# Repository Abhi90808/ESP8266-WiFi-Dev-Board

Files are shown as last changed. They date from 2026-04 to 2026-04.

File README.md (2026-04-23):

# ESP8266 WiFi Development Board

A custom ESP8266-based WiFi development board designed in KiCad 8, featuring onboard USB-to-serial, 3.3V regulation, and a breadboard-friendly pinout — perfect for IoT prototyping.

---

## Features
- ESP8266 (ESP-12E/F module) WiFi MCU
- Onboard USB-to-Serial (CH340G)
- 3.3V LDO regulator (AMS1117-3.3)
- Auto-reset circuit for one-click flashing
- All GPIO pins broken out to 2.54mm headers
- Flash and Reset buttons onboard
- Power LED and user LED (GPIO2)

## Specifications

| Parameter | Value |
|---|---|
| Module | ESP-12E / ESP-12F |
| MCU | Tensilica L106 (32-bit) |
| Clock Speed | 80MHz / 160MHz |
| WiFi | 802.11 b/g/n (2.4GHz) |
| Operating Voltage | 3.3V |
| USB Input | 5V via Micro USB |
| Flash Memory | 4MB |
| GPIO Pins | 11 usable |
| PCB Layers | 2 |
| Designed With | KiCad 8 |

## Project Structure

```
├── Schematic/       # KiCad schematic (.kicad_sch, PDF)
├── PCB/             # PCB layout (.kicad_pcb, .kicad_pro)
├── Gerbers/         # Fabrication files
├── BOM/             # Bill of materials (CSV)
├── 3D/              # 3D model (.step)
└── Images/          # PCB renders and schematic screenshots
```

## How It Works

The CH340G converts USB to UART for programming. The auto-reset circuit uses transistors on the DTR/RTS lines to automatically pull GPIO0 LOW and reset the ESP8266 before flashing — no manual button pressing needed.

## Programming

1. Install the ESP8266 board in Arduino IDE via Boards Manager
2. Select **Generic ESP8266 Module** or **NodeMCU 1.0**
3. Connect via Micro USB and select the correct COM port
4. Upload directly — auto-reset handles the rest

## Bill of Materials (Summary)

| Component | Value | Qty |
|---|---|-----|
| WiFi Module | ESP-12F | 1 |
| USB-Serial IC | CH340G | 1 |
| LDO Regulator | AMS1117-3.3V | 1 |
| Capacitors | 100nF, 10µF | 4 |
| Transistors | BC817 | 2 |
| Buttons | Tactile | 2 |
| USB Connector | Micro-B | 1 |

## Fabrication

Gerber files are in `/Gerbers`, ready for JLCPCB, PCBWay, or similar.

## License

This project is licensed under the [CERN Open Hardware Licence Version 2 - Strongly Reciprocal (CERN OHL-S v2)](https://ohwr.org/cern_ohl_s_v2.txt).

## Author

**Abhi90808** — [GitHub Profile](https://github.com/Abhi90808)

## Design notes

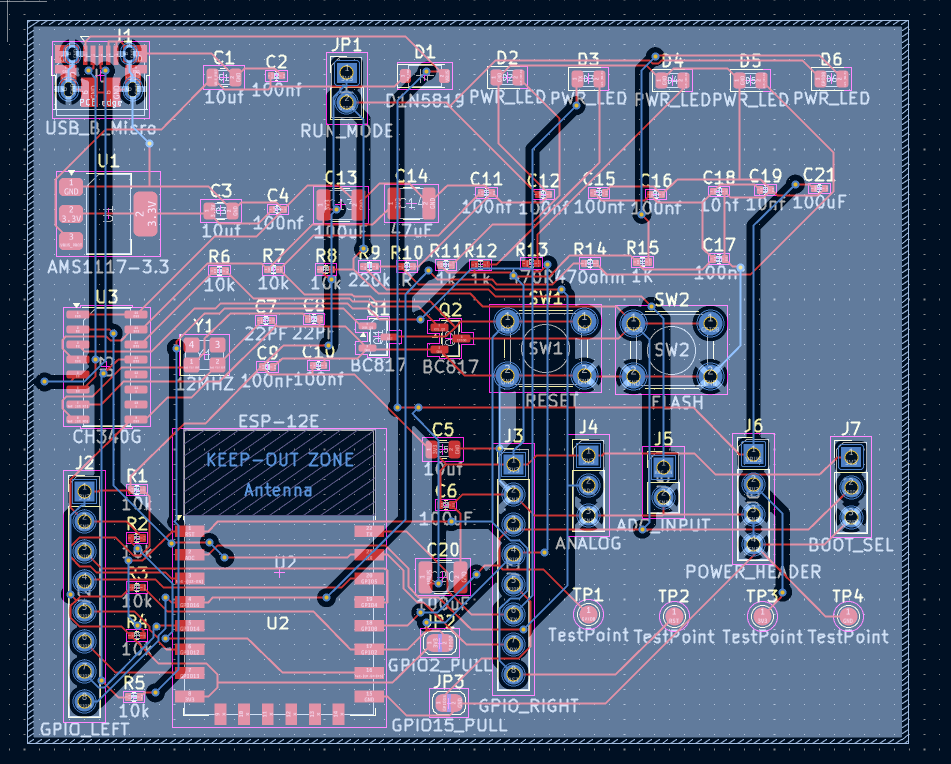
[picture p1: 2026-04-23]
Screenshot 2026-04-21 175008.png

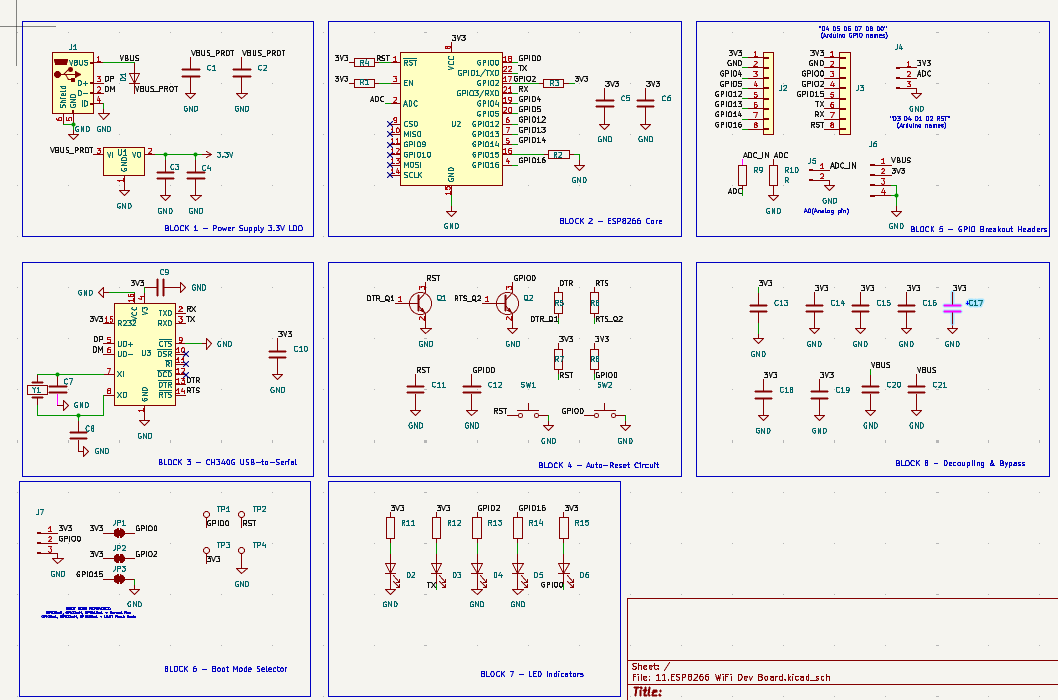
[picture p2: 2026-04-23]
Screenshot 2026-04-21 175130.png

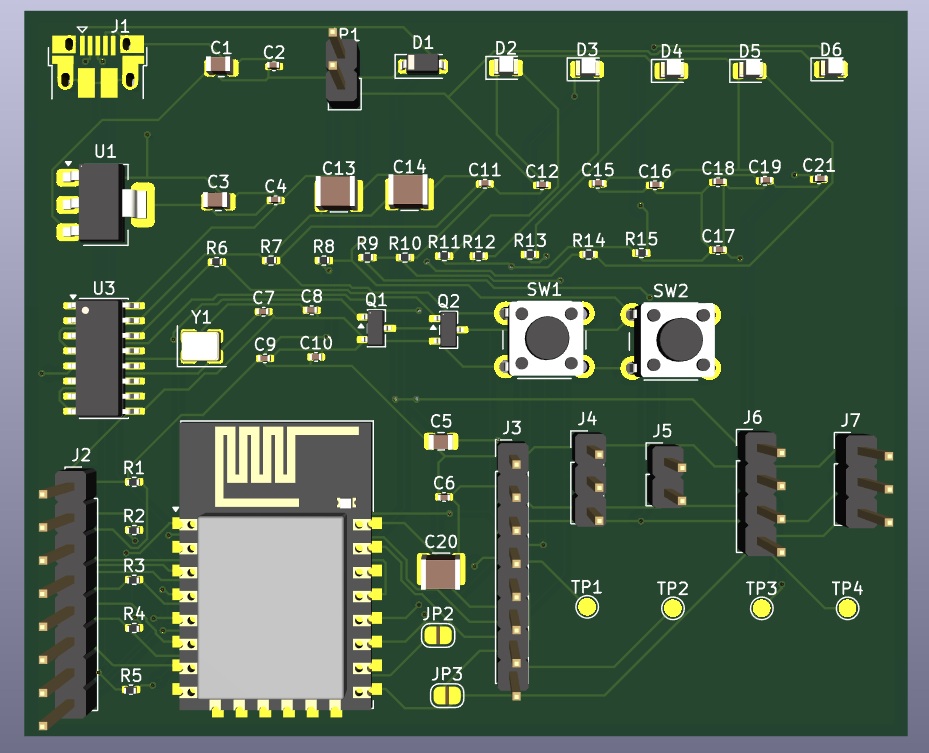
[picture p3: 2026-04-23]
Screenshot 2026-04-21 175057.png

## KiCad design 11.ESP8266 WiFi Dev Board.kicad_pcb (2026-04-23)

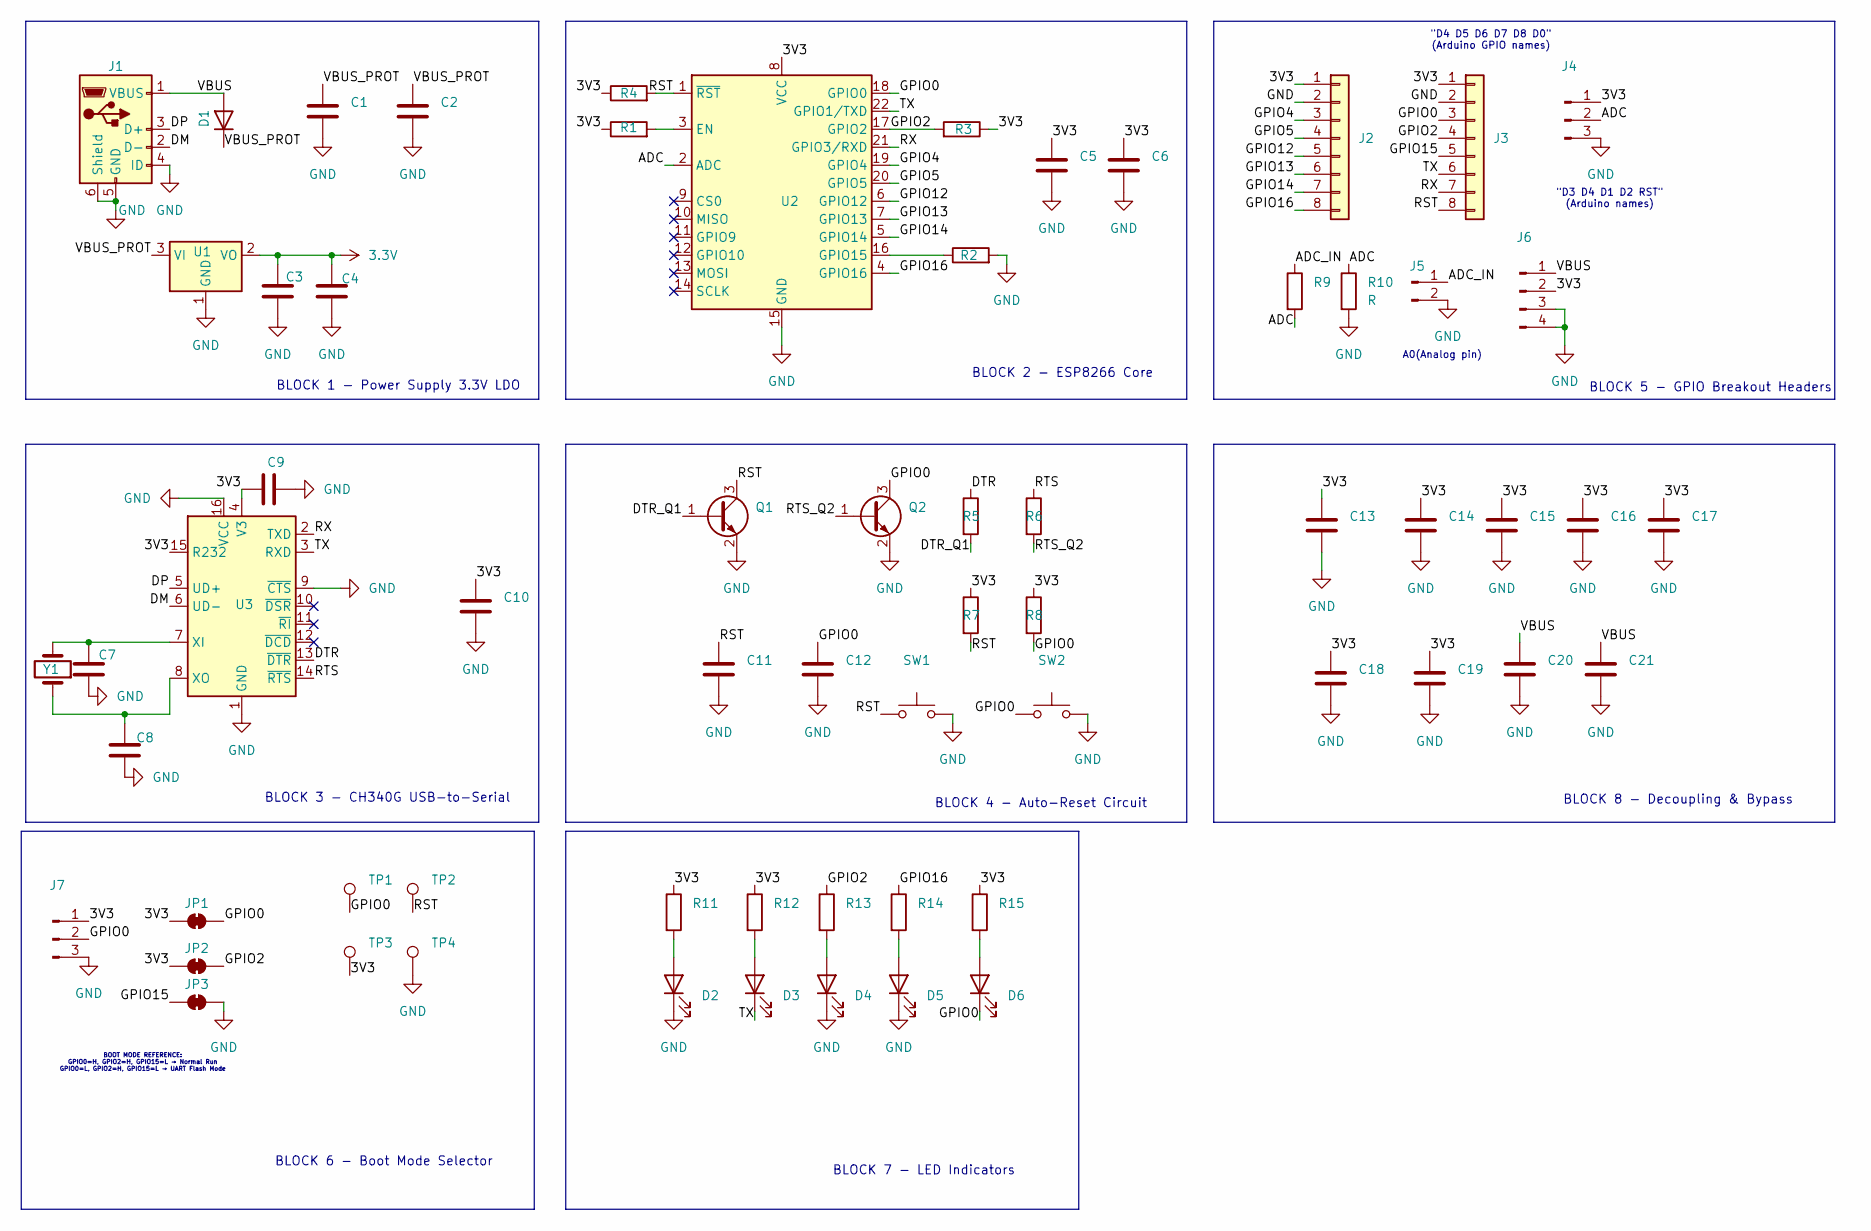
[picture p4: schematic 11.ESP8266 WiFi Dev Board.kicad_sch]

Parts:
C1, C3, C5: 10uf; C_0805_2012Metric
C2, C4, C10, C11, C12, C15, C16, C17: 100nf; C_0402_1005Metric
C6, C21: 100uF; C_0402_1005Metric
C7, C8: 22PF; C_0402_1005Metric
C9: 100nF; C_0402_1005Metric
C13, C20: 100uF; C_1210_3225Metric
C14: 47uF; C_1210_3225Metric
C18, C19: 10nf; C_0402_1005Metric
D1: D1N5819; D_SOD-123
D2, D3, D4, D5, D6: PWR_LED; LED_0805_2012Metric
J1: USB_B_Micro; USB_Micro-B_Amphenol_10103594-0001LF_Horizontal
J2: GPIO_LEFT; PinHeader_1x08_P2.54mm_Vertical
J3: GPIO_RIGHT; PinHeader_1x08_P2.54mm_Vertical
J4: ANALOG; PinHeader_1x03_P2.54mm_Vertical
J5: ADC_INPUT; PinHeader_1x02_P2.54mm_Vertical
J6: POWER_HEADER; PinHeader_1x04_P2.54mm_Vertical
J7: BOOT_SEL; PinHeader_1x03_P2.54mm_Vertical
JP1: RUN_MODE; PinHeader_1x02_P2.54mm_Vertical
JP2: GPIO2_PULL; SolderJumper-2_P1.3mm_Open_RoundedPad1.0x1.5mm
JP3: GPIO15_PULL; SolderJumper-2_P1.3mm_Open_RoundedPad1.0x1.5mm
Q1, Q2: BC817; SOT-23
R1, R2, R3, R4, R5, R6, R7, R8: 10k; R_0402_1005Metric
R9: 220k; R_0402_1005Metric
R10: R; R_0402_1005Metric
R11, R12: 1k; R_0402_1005Metric
R13: 470R; R_0402_1005Metric
R14: 470ohm; R_0402_1005Metric
R15: 1K; R_0402_1005Metric
SW1: RESET; SW_PUSH_6mm_H5mm
SW2: FLASH; SW_PUSH_6mm_H5mm
TP1, TP2, TP3, TP4: TestPoint; TestPoint_Pad_D1.5mm
U1: AMS1117-3.3; SOT-223-3_TabPin2
U2: ESP-12E
U3: CH340G; SOIC-16_3.9x9.9mm_P1.27mm
Y1: 12MHZ; Crystal_SMD_3225-4Pin_3.2x2.5mm

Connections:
3.3V: C3.1, C4.1, U1.2 (VO)
/3V3: C5.1, C6.1, C9.1, C10.1, C13.1, C14.1, C15.1, C16.1, C17.1, C18.1, C19.1, J2.1, J3.1, J4.1, J6.2, J7.1, JP1.1 (A), JP2.1 (A), R1.1, R3.1, R4.1, R7.1, R8.1, R11.1, R12.1, R15.1, TP3.1, U2.8 (VCC), U3.4 (V3), U3.15 (R232)
/ADC: J4.2, R9.2, R10.1, U2.2 (ADC)
/ADC_IN: J5.1, R9.1
/DM: J1.2 (D-), U3.6 (UD-)
/DP: J1.3 (D+), U3.5 (UD+)
/DTR: R5.1, U3.13 (~DTR)
/DTR_Q1: Q1.1 (B), R5.2
/GPIO0: C12.1, D6.1 (K), J3.3, J7.2, JP1.2 (B), Q2.3 (C), R8.2, SW2.1, TP1.1, U2.18 (GPIO0)
/GPIO2: J3.4, JP2.2 (B), R3.2, R13.1, U2.17 (GPIO2)
/GPIO4: J2.3, U2.19 (GPIO4)
/GPIO5: J2.4, U2.20 (GPIO5)
/GPIO12: J2.5, U2.6 (GPIO12)
/GPIO13: J2.6, U2.7 (GPIO13)
/GPIO14: J2.7, U2.5 (GPIO14)
/GPIO15: J3.5, JP3.1 (A)
/GPIO16: J2.8, R14.1, U2.4 (GPIO16)
/RST: C11.1, J3.8, Q1.3 (C), R4.2, R7.2, SW1.1, TP2.1, U2.1 (~RST)
/RTS: R6.1, U3.14 (~RTS)
/RTS_Q2: Q2.1 (B), R6.2
/RX: J3.7, U2.21 (GPIO3/RXD), U3.2 (TXD)
/TX: D3.1 (K), J3.6, U2.22 (GPIO1/TXD), U3.3 (RXD)
/VBUS: C20.1, C21.1, D1.2 (A), J1.1 (VBUS), J6.1
/VBUS_PROT: C1.1, C2.1, D1.1 (K), U1.3 (VI)
GND: C1.2, C2.2, C3.2, C4.2, C5.2, C6.2, C7.2, C8.2, C9.2, C10.2, C11.2, C12.2, C13.2, C14.2, C15.2, C16.2, C17.2, C18.2, C19.2, C20.2, C21.2, D2.1 (K), D4.1 (K), D5.1 (K), J1.4 (ID), J1.5 (GND), J1.6 (Shield), J2.2, J3.2, J4.3, J5.2, J6.3, J6.4, J7.3, JP3.2 (B), Q1.2 (E), Q2.2 (E), R2.2, R10.2, SW1.2, SW2.2, TP4.1, U1.1 (GND), U2.15 (GND), U3.1 (GND), U3.9 (~CTS), U3.16 (VCC)
unnamed: D2.2 (A), R11.2
unnamed: D3.2 (A), R12.2
unnamed: D4.2 (A), R13.2
unnamed: D5.2 (A), R14.2
unnamed: D6.2 (A), R15.2
unnamed: R1.2, U2.3 (EN)
unnamed: R2.1, U2.16 (GPIO15)
unnamed: C7.1, U3.7 (XI), Y1.2
unnamed: C8.1, U3.8 (XO), Y1.1

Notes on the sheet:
BLOCK 1 - Power Supply 3.3V LDO
BLOCK 4 - Auto-Reset Circuit
BLOCK 2 - ESP8266 Core
"D4 D5 D6 D7 D8 D0" (Arduino GPIO names)
BLOCK 3 - CH340G USB-to-Serial
A0(Analog pin)
BOOT MODE REFERENCE: GPIO0=H, GPIO2=H, GPIO15=L → Normal Run GPIO0=L, GPIO2=H, GPIO15=L → UART Flash Mode
BLOCK 5 - GPIO Breakout Headers
BLOCK 8 - Decoupling & Bypass
"D3 D4 D1 D2 RST" (Arduino names)
BLOCK 7 - LED Indicators
BLOCK 6 - Boot Mode Selector

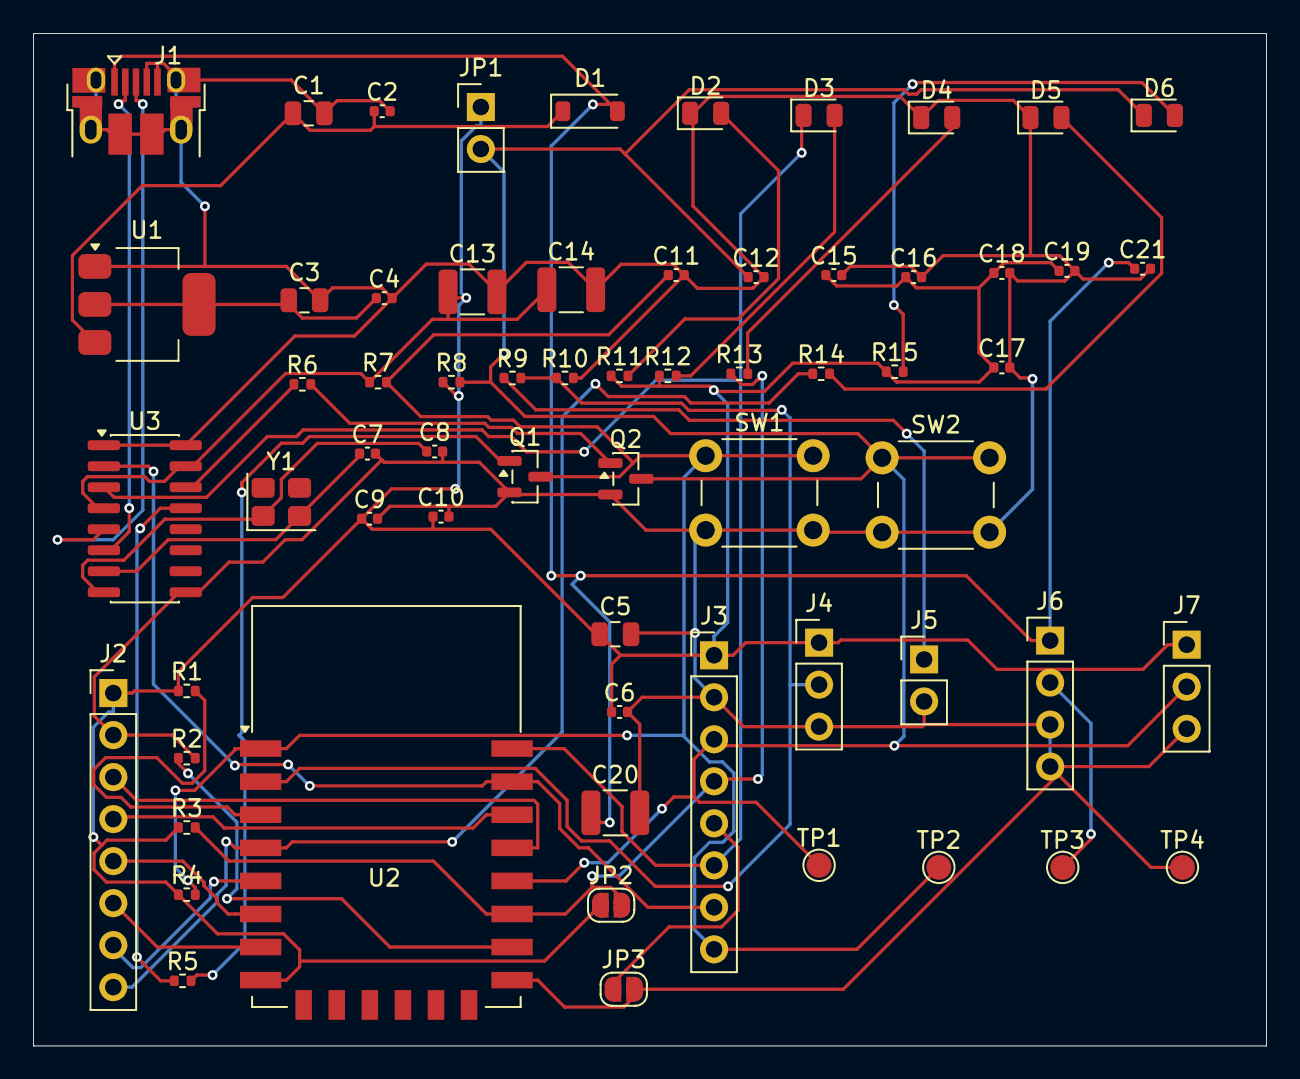
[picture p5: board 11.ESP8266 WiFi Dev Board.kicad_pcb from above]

Board: 2 copper layers, 74.5 x 61.2 mm, 64 parts (0 on the bottom side), 34 nets.
